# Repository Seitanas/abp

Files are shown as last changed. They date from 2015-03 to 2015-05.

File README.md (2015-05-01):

AntiBurglar-pi  
=====  
  
Home security system, based on raspberry-pi.  
System monitors two security zones, two temperature zones. Uses gnokii to send sms via gsm phone or modem, activates 
siren via relay.  
Also monitors status of powerline, reports if power is down.  
System control is done via SMS commands:  
  
<b>arm password</b> (e.g arm 1111) - system is armed instantly.  
<b>disarm password</b> - armed system deactivates after receiving SMS.  
<b>status password</b> - system responds with device uptime and temperature status after receiving SMS.  
<b>siren on password</b> - siren is turned on.  
<b>siren off password</b> - siren is turned off.  
  
When triggered, alarm warning is sent do a predefined number in config.h file.  
  
Edit src/config.h to fit your needs.  
You need to install libgnokii development libraries, also wiringpi:  
http://wiringpi.com/download-and-install/  
Make sure to create /etc/gnokii.conf config file with configuration for your GSM modem or phone.  
Example of working gnokii.conf file with "Huawei Technologies Co., Ltd. E220 HSDPA Modem / E230/E270/E870 HSDPA/HSUPA" modem:  
  
[global]  
model = AT  
port = /dev/ttyUSB0  
connection = serial  

To build and install system  
make  
make install  

If using raspbian distribution, copy init script from debian_init folder  
to /etc/init.d/ folder. 
Start antiburglar-pi with /etc/init.d/abp start  
  
More information about this project can be found at:  
http://www.neblogas.lt/2015/03/31/antiburglar-pi/  

v0.1c extended status report info.  
v0.1b some additional features.    
v0.1a some fixes, init scripts.  
v0.1 Initial release

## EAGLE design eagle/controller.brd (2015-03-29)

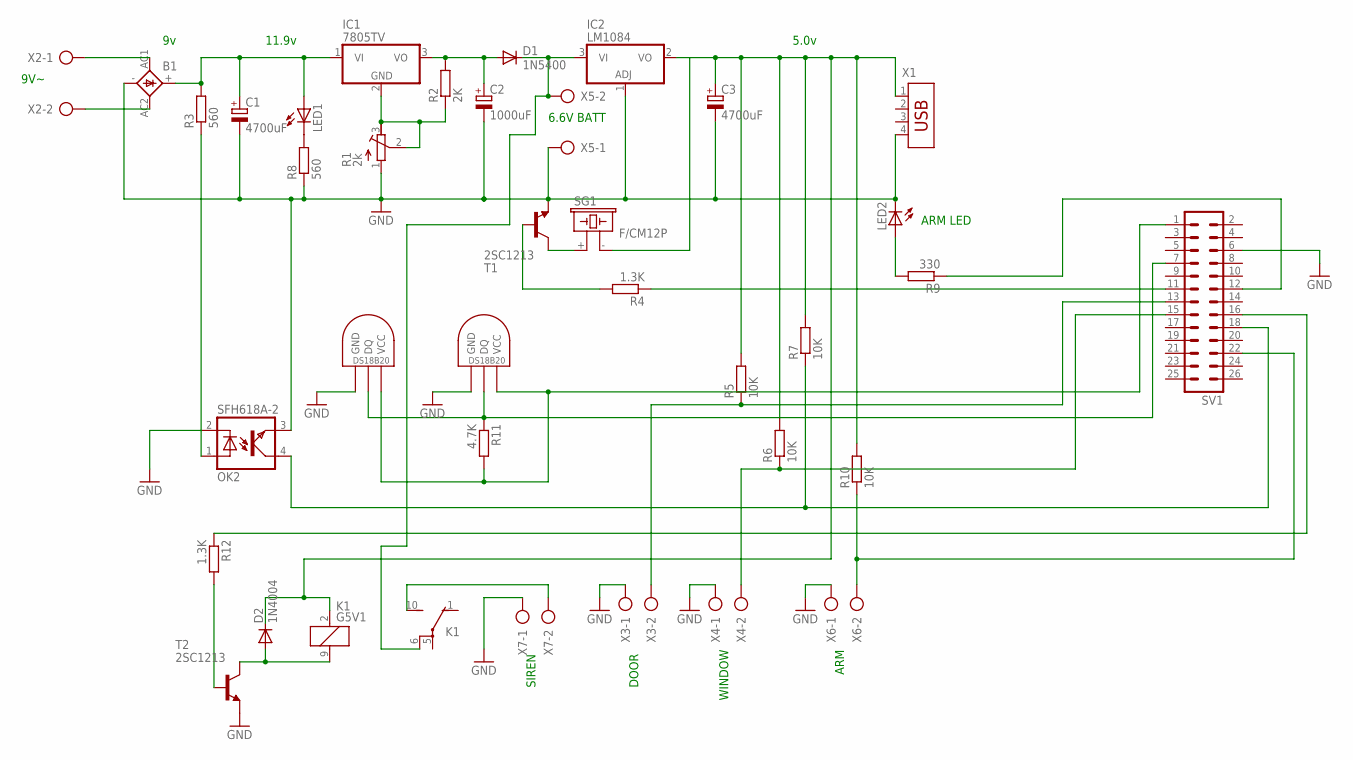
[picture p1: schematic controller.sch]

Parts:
B1: S41
C1, C3: 4700uF; E5-13
C2: 1000uF; E5-10,5
D1: 1N5400; DO201-15
D2: 1N4004; DO41-10
IC1: 7805TV; TO220V
IC2: LM1084; TO220V
K1: G5V1
LED1, LED2: LED5MM
OK2: SFH618A-2; DIP4
R1: 2k; RTRIM64W
R2: 2K; 0204/7
R3, R8: 560; 0204/7
R4, R12: 1.3K; 0204/7
R5, R6, R7, R10: 10K; 0204/7
R9: 330; 0204/7
R11: 4.7K; 0204/7
SG1: F/CM12P
SV1: ML26L
T1, T2: 2SC1213; TO92-EBC
U$1, U$2: DS1820TO92; DS1820
X1: USB-787616; USB
X2, X3, X4, X5, X6, X7: AK500/2

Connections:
GND: B1.-, C1.-, C2.-, C3.-, IC2.1 (ADJ), LED2.K (C), OK2.2 (C), OK2.3 (EMIT), R1.1 (E), R8.1, SV1.6, T1.E, T2.E, U$1.GND, U$2.GND, X1.4, X3.1, X4.1, X5.1, X6.1, X7.1
unnamed: IC1.2 (GND), R1.2 (S), R1.3 (A), R2.1
unnamed: R12.2, T2.B
unnamed: D2.A, K1.9 (2), T2.C
unnamed: C2.+, D1.A, IC1.3 (VO), R2.2
unnamed: B1.AC2, X2.2
unnamed: B1.AC1, X2.1
unnamed: B1.+, C1.+, IC1.1 (VI), LED1.A, R3.2
unnamed: OK2.1 (A), R3.1
unnamed: OK2.4 (COL), R7.1, SV1.18
unnamed: R4.2, T1.B
unnamed: R4.1, SV1.11
unnamed: SG1.+ (1), T1.C
unnamed: R5.1, SV1.13, X3.2
unnamed: LED1.K (C), R8.2
unnamed: R6.1, SV1.15, X4.2
unnamed: LED2.A, R9.2
unnamed: R9.1, SV1.12
unnamed: R10.1, SV1.22, X6.2
unnamed: R11.1, SV1.7, U$1.DQ, U$2.DQ
unnamed: R11.2, SV1.1, U$1.VDD (VCC), U$2.VDD (VCC)
unnamed: R12.1, SV1.16
unnamed: C3.+, D2.C, IC2.2 (VO), K1.2 (1), R5.2, R6.2, R7.2, R10.2, SG1.- (2), X1.1
unnamed: K1.10 (S), X7.2
unnamed: D1.C, IC2.3 (VI), K1.6, X5.2

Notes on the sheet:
5.0v
11.9v
DOOR
WINDOW
ARM
ARM LED
6.6V BATT
9V~
SIREN

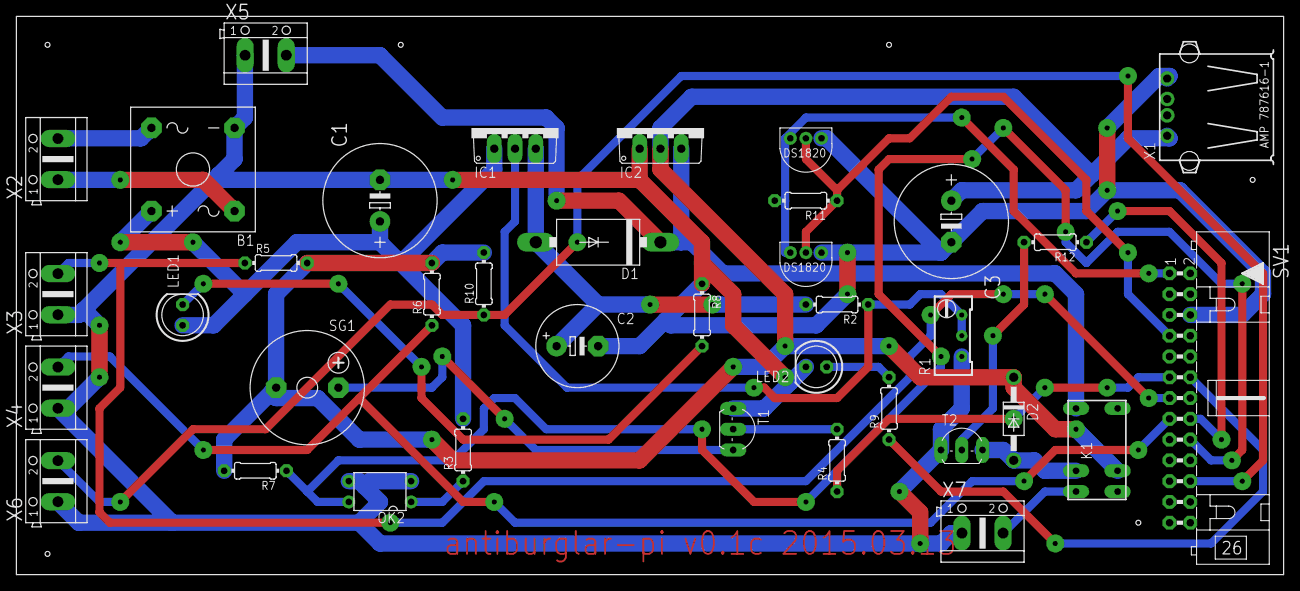
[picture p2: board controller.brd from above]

Board: 2 copper layers, 154.9 x 68.2 mm, 37 parts (0 on the bottom side), 25 nets.

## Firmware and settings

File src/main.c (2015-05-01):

/*
    antiburglar-pi
    Tadas Ustinavičius
    2015-05-01
*/


#include "sms.h"
#include <stdio.h>
#include <sys/sysinfo.h>
#include <locale.h>
#include "globals.h"
#include <wiringPi.h>
#include <pthread.h>
#include "syslog.h"
#include <stdlib.h>
#include "config.h"
int door=0, window=0, pwr=0,arm=0;
int door_sent=0, window_sent=0, pwr_sent=0, arm_sent=0;


void init_gpio(void){
    wiringPiSetup ();    
    pinMode (BUZZER, OUTPUT) ;
    pinMode (ARMED_LED, OUTPUT);
    pinMode(DOOR, INPUT);
    pinMode(WINDOW, INPUT);
    pinMode(POWER, INPUT);
    pinMode(ARM_BUTTON, INPUT);
    pinMode(SIREN, OUTPUT);
    digitalWrite (BUZZER, LOW) ;
    digitalWrite (ARMED_LED, LOW) ;
    digitalWrite (SIREN, LOW);
}


void read_sensors(void){ //read all GPIO inputs, except temperature.
    door=digitalRead(DOOR);
    window=digitalRead(WINDOW);
    pwr=digitalRead(POWER);
    arm=digitalRead(ARM_BUTTON);
}

void * armed_blink(){//blinks LED while system is armed.
    while (armed){
	digitalWrite (ARMED_LED, HIGH) ;
        usleep(200000);
        digitalWrite (ARMED_LED, LOW) ;
	usleep(200000);
    }
    digitalWrite(ARMED_LED,LOW); //reset signal to low
    pthread_exit(0);
}

void arm_beep(void){//beep for period of arming_seconds.
    int x=ARMING_SECONDS*2;
    while (x!=0){
	int pulse=0;
	while (pulse!=100){
	    ++pulse;
	    digitalWrite(BUZZER,HIGH);
	    usleep(650);
	    digitalWrite(BUZZER,LOW);
	    usleep(650);
	}
	usleep(400000);
	--x;
    }
    x=3;
    while (x!=0){//emit 3 short beeps to inform, that system is armed
	int pulse=0;
	while (pulse!=30){
	    ++pulse;
	    digitalWrite(BUZZER,HIGH);
	    usleep(300);
	    digitalWrite(BUZZER,LOW);
	    usleep(300);
	}
	usleep(200000);
	--x;
    }	
    digitalWrite(BUZZER,LOW); //reset signal to low
}

void disarm_beep(){
    int x=4;
    while (x!=0){
	int pulse=0;
	while (pulse!=30){
	    ++pulse;
	    digitalWrite(BUZZER,HIGH);
	    usleep(340);
	    digitalWrite(BUZZER,LOW);
	    usleep(300);
	}
	usleep(200000);
	--x;
    }	
    digitalWrite(BUZZER,LOW); //reset signal to low
}
int read_temp(char *device_path){
    FILE *fp;
    char tmp[80],tmp2[80];
    char junk[80],crc[5],crc2[5];
    int value=0;
    if ((fp = fopen(device_path,"r")) != (FILE *)NULL) {
	fgets(tmp,80,fp); /* Get first line w/ checksums */
        fgets(tmp2,80,fp); /* Get 2nd line w/ temp */
	sscanf(tmp,"%[^:]: %[^ ] %s\n",junk,crc,crc2);
        sscanf(tmp2,"%[^=]=%d\n",junk,&value);
	fclose(fp);
    }
    return value;
}
void daemon(){
        pid_t mypid;
        FILE *pid;
        mypid=fork();
        if (mypid){
                pid=fopen("/var/run/abp/abp.pid","w");
                fprintf(pid,"%i",mypid);
                exit (0);
        }
}
void system_exit(void){
    syslog_write("Stopping antiburglar-pi");
}
void call_led_thread(void){
    pthread_t tid;
    pthread_create(&tid,NULL,armed_blink,NULL);
    pthread_detach(tid);
}
int main (void){
    exit;
    atexit (system_exit);
    syslog_write("Starting antiburglar-pi");
    init_gpio();
    disarm_beep(); //beep at system startup
    daemon();
    setlocale(LC_ALL, "");
    sleep (1); //wait for dust to settle
    armed=0;
    char temp_message[200];
    int door_sent=0, window_sent=0, power_sent=0;
    int timer=0;
    while (1){//main loop
        read_sensors();
	++timer;
        if (!armed&&!arm){//arm button pressed. gpio pin low
            arm_beep();
            read_sensors();
	    armed=1;
	    gnokii_send(RECIPIENT,"System armed.");
	    syslog_write("System armed.");
	    call_led_thread();
        }
	if (armed&&door&&!door_sent){//system is armed, door was opened, sms was not sent
	    gnokii_send(RECIPIENT,"Door is open, triggering alarm.");
	    digitalWrite(SIREN,HIGH);
	    door_sent=1;
	    syslog_write("Door is open, triggering alarm.");
	}
	if (armed&&window&&!window_sent){//system is armed, window was opened, sms was not sent
	    gnokii_send(RECIPIENT,"Window is open, triggering alarm");
	    digitalWrite(SIREN,HIGH);
	    window_sent=1;
	    syslog_write("Window is open, triggering alarm");
	}
	if (pwr&&!power_sent){
	    power_sent=1;
	    gnokii_send(RECIPIENT,"Power loss detected");
	    syslog_write("Power loss detected");
	}
	if (!pwr&&power_sent){
	    power_sent=0;
	    gnokii_send(RECIPIENT,"Power is back to normal");
	    syslog_write("Power is back to normal");
	}
	if (timer==300){//check inbox every minute 
    	    getsms();
    	    timer=0;
	}
        if (send_status){
	    float temp1=0,temp2=0;
	    temp1=read_temp(SENSOR1);
	    temp2=read_temp(SENSOR2);
    	    send_status=0;
    	    struct sysinfo info;
    	    sysinfo(&info);
	    int days = info.uptime / (60 * 60 * 24);
	    info.uptime -= days * (60 * 60 * 24);
	    int hours = info.uptime / (60 * 60);
	    info.uptime -= hours * (60 * 60);
	    int minutes = info.uptime / 60;
	    info.uptime -= minutes * 60;
	    char uptime[160];
	    char window_status[10];
	    char door_status[10];
	    char arm_status[10];
	    char siren_status[10];
	    if (window)
		sprintf(window_status,"open. ");
	    else
		sprintf(window_status,"closed. ");
	    if (door)
		sprintf(door_status,"open. ");
	    else
		sprintf(door_status,"closed. ");
	    if (digitalRead(SIREN))
	    	sprintf(siren_status,"on. ");
	    else
		sprintf(siren_status,"off. ");
	    if (armed)
		sprintf(arm_status,"armed.");
	    else
		sprintf(arm_status,"disarmed.");
    	    sprintf(uptime,"UP: %i days, %i hours, %i minutes, %i seconds. Load average: %.2f %.2f %.2f Temp1: %.2f Temp2: %.2f. Window: %sDoor: %sSiren: %sSystem: %s",days,hours,minutes, info.uptime,info.loads[0]/65536.0, info.loads[1]/65536.0, info.loads[2]/65536.0,temp1/1000,temp2/1000,window_status,door_status,siren_status,arm_status);
	    sprintf(temp_message,"Client %s is requesting status.",sms_sender);	    
	    syslog_write(temp_message);
	    sprintf(temp_message,"Replying with %s",uptime);
	    syslog_write(temp_message);
	    gnokii_send(sms_sender,uptime);
	}
	if (disarm){
	    disarm=0;
	    armed=0;
	    door_sent=0;
	    window_sent=0;
	    power_sent=0;
	    digitalWrite(SIREN,LOW);
	    syslog_write("System disarmed");
	    gnokii_send(sms_sender,"System disarmed");
	    disarm_beep();
	}
    usleep (200000);
    }
}
